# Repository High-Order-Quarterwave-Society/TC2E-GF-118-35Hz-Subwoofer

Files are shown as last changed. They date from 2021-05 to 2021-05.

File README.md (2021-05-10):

# Type C2E-GF-118 rev: 42.11
The TC2E-GF-118 Golden Formula Paraflex subwoofer was originaly designed by Matthew Morgan J. member of the **Higher Order Quarterwave Society** (HOQWS) which was started in 2013 by Matthew Morgan J, Dustin Morgan (Flex Tech Designs) and J. Vansickle (Paragon Concepts) 

### About Paraflex
The Paraflex subwoofer is based on a Low and High Tuned Resonator (LTR/HTR) making the design very efficient in it's bandwidth, which was named **Paraflex** for easy naming. Many prototypes and design revisions have been made by members of the HOQWS, continualy improving the design of the cabinet and its different versions.

The Golden Formula series of Paraflex subwoofers achieves improved performance by the use of a Throat Chamber in conjunction with an increased rate of expansion in the Low-Tuned Horn resonator section. This increased gain/sensitivity & output within the cabinet's working range, typically comes at the cost of sacrificing some surplus upper extension and can also often require a larger cabinet size. 

## Updates
The TC2E-GF-118 Revision 42.11 is the latest update for the TC2E-GF-118.

#### Folded High-Tune Resonator (HTR)
New 410mm long 45 degree angle-brace panels (which also serve as the folded & offset portion of the high-tuned resonator) have increased the upper frequency extension (cut-off) to 180hz and improved the cabinet's phase response, transient response, and impulse response, while reducing gd & decay times in the cabinet's upper working range above 80hz.

#### HTR filling
Acoustic damping material such as polyester fiberfill should be added to the angle braces. insert the damping material until it fills up 50% to 60% of the angle-brace's internal volume beginning from the end caps. 

#### Mouth brace update
A mouth brace has now been included to reduce flex in the mouth exit area, and with the updated merge bracing shape; a b&c 18ds115 is capable of fitting past on an angle. longer drivers will require shortening the brace or making it removable.

## Dimensions / Volume
Dimensions shall be 1200 x 915 x 600 milimeters and shall have 658 Liters Gross volume. The unloaded weight shall be 97Kg / 213Lbs.

## Working range
The TC2E-GF-118 has a 35Hz (Fb) tuning and the working range shall be 30hz to 180hz. Recomended crossover setting depends on the driver used, but a basic setting can be set with a 26-30hz 24dB/Butterworth Highpass filter (24dB/BW HPF) and a 75-160hz Butterworth 4th order low pass filter (24dB/BW LPF). We encourage the user to adjust the frequency range and filters based on their application.

## PDF
[You can download the PDF here](https://github.com/High-Order-Quarterwave-Society/TC2E-GF-118-35Hz-Subwoofer/blob/master/PARAFLEX%20C-2E%20Golden%20Formula%201x18%20v42.11.pdf)

## More...
Other designs using the Paraflex principles where made for midrange and infrasonic frequency ranges. There are always new concepts and designs in progress on the [HOQWS facebook page](https://www.facebook.com/groups/bassaz/).

*3D design by Ty Cention. (KaiRonex)*

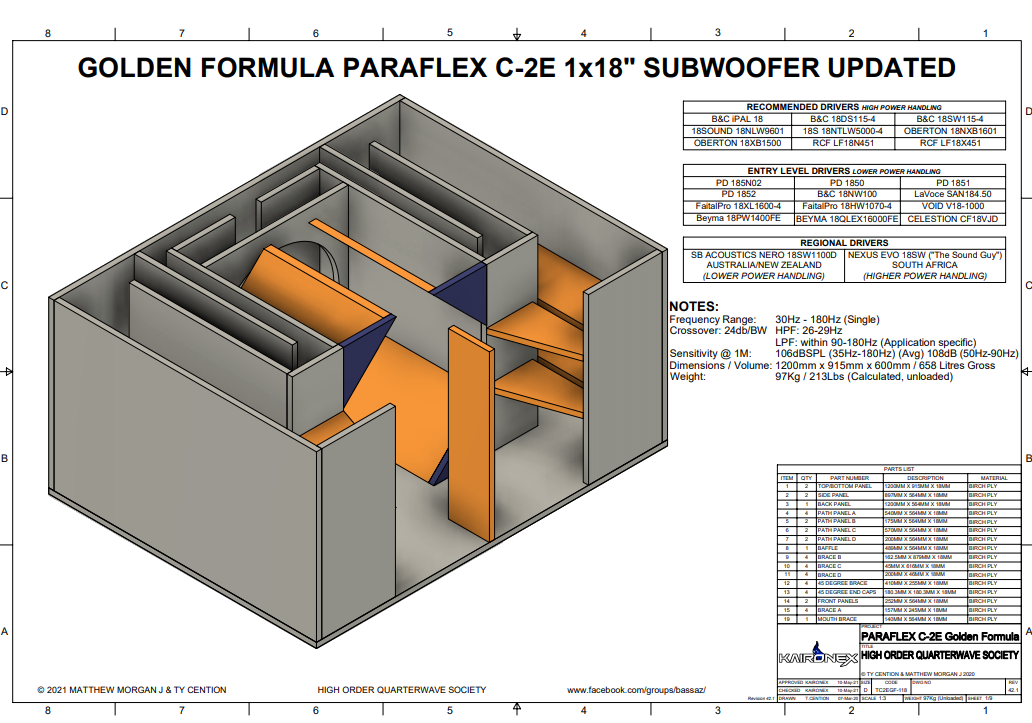
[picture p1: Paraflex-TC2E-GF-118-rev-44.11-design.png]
Design


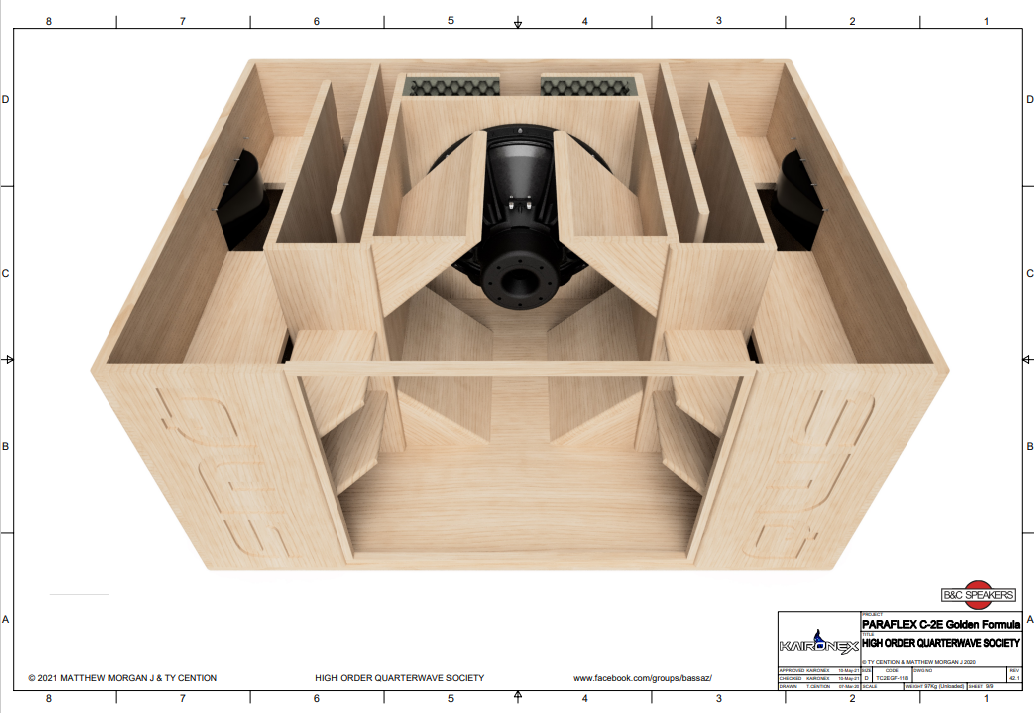
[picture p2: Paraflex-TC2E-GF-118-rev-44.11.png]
Modal view


 #### Honorable contributers and people from all arround the world who shared their knowledge, time, testing builds, prototyping, art work, design work and so much more to the HOQS group:
Ty Cention, Josh Mullins, Philip van Heijningen, Patrick Sander, Val Boodram, Justin Crescendo, Angel Garabitos Romero, Jason Geban, Andre Schrock, Casey Raynes, Conor Noakes, Nicolai Grymer and many more.

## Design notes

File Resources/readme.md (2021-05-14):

# Recources for the cabinet

CAD files, cutlists, CNC cut plans, etc.

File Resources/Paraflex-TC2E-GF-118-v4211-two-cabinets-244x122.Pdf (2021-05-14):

Birch 2440x1220x18 mm

Sheet Size : 2440 mm x 1220 mm

Cutting List

Symbol | Length | Width | Qty
1 | 1210 mm 925 mm | 2
2 | 670 mm 564 mm | 1
3 | 540 mm 564 mm | 1

# Job Layout

Job Reference : PARAFLEX-TC2E-GF-118 v42.11
Client Name : | Layout 1 of 6 (x1) - Birch 2440x1220x18 mm (2440 mm x 1220 mm)
Date Required : 27-5-2021 | Occurrences : 1 | Total Sheets : 6
Phone Number : | Sheet Panels : 4 | Job Panels : 76
Fax Number : | Layout Wastage : 1,88% | Job Wastage : 6,36%
Cell No : | Sheet Cut Length : 6632 mm | Job Cut Length : 73988 mm

1220 mm

2440 mm

1.TOP

1210 mm

925 mm

1.TOP

1210 mm

925 mm

2.PP C

670 mm

564 mm

3.PP A

540 mm

564 mm

### Grain Direction

### Occurrences

x1

Generated using MaxCut - visit www.maxcutsoftware.com to get your free copy | 14-5-2021

Cutting List

Symbol | Length | Width | Qty
1 | 1200 mm 915 mm | 2
2 | 670 mm 564 mm | 1
3 | 540 mm 564 mm | 1

Job Reference : PARAFLEX-TC2E-GF-118 v42.11
Client Name : | Layout 2 of 6 (x1) - Birch 2440x1220x18 mm (2440 mm x 1220 mm)
Date Required : 27-5-2021 | Occurrences : 1 | Total Sheets : 6
Phone Number : | Sheet Panels : 4 | Job Panels : 76
Fax Number : | Layout Wastage : 3,30% | Job Wastage : 6,36%
Cell No : | Sheet Cut Length : 6602 mm | Job Cut Length : 73988 mm
| 1220 mm

2440 mm

1.BOTTOM

1200 mm

915 mm

1.BOTTOM

1200 mm

915 mm

2.PP C

670 mm

564 mm

3.PP A

540 mm

564 mm

### Grain Direction

### Occurrences

x1

Cutting List

Symbol | Length | Width | Qty
1 | 1200 mm 564 mm | 2
2 | 897 mm 564 mm | 2
3 | 162,5 mm 879 mm | 1
4 | 252 mm 564 mm | 2
5 | 157 mm 245 mm | 1
6 | 200 mm | 46 mm | 3

Job Reference : PARAFLEX-TC2E-GF-118 v42.11
Client Name : | Layout 3 of 6 (x1) - Birch 2440x1220x18 mm (2440 mm x 1220 mm)
Date Required : 27-5-2021 | Occurrences : 1 | Total Sheets : 6
Phone Number : | Sheet Panels : 11 | Job Panels : 76
Fax Number : | Layout Wastage : 3,97% | Job Wastage : 6,36%
Cell No : | Sheet Cut Length : 11304 mm | Job Cut Length : 73988 mm
| 1220 mm

2440 mm

1.BACK

1200 mm

564 mm

1.BACK

1200 mm

564 mm

2.SIDE

897 mm

564 mm

2.SIDE

897 mm

564 mm

3.BR B 879 mm

162,5 mm

4.FP

252 mm

564 mm

4.FP

252 mm

564 mm

5.BR A 245 mm

157 mm

6.BR D 6.BR D 6.BR D

### Grain Direction

### Occurrences

x1

Cutting List

Symbol | Length | Width | Qty
1 | 489 mm 564 mm | 2
2 | 670 mm 564 mm | 2
3 | 897 mm 564 mm | 2
4 | 360 mm 564 mm | 2
5 | 45 mm | 616 mm | 2
6 | 200 mm | 46 mm | 2

Job Reference : PARAFLEX-TC2E-GF-118 v42.11
Client Name : | Layout 4 of 6 (x1) - Birch 2440x1220x18 mm (2440 mm x 1220 mm)
Date Required : 27-5-2021 | Occurrences : 1 | Total Sheets : 6
Phone Number : | Sheet Panels : 12 | Job Panels : 76
Fax Number : | Layout Wastage : 5,97% | Job Wastage : 6,36%
Cell No : | Sheet Cut Length : 12310 mm | Job Cut Length : 73988 mm
| 1220 mm

2440 mm

1.BAFFLE

564 mm

489 mm
1.BAFFLE

564 mm

489 mm

2.PP C

564 mm

670 mm

2.PP C

564 mm

670 mm

3.SIDE

564 mm

897 mm

3.SIDE

564 mm

897 mm

4.PP B

564 mm

360 mm
4.PP B

564 mm

360 mm

5.BR C 5.BR C 6.BR D 6.BR D

### Grain Direction

### Occurrences

x1

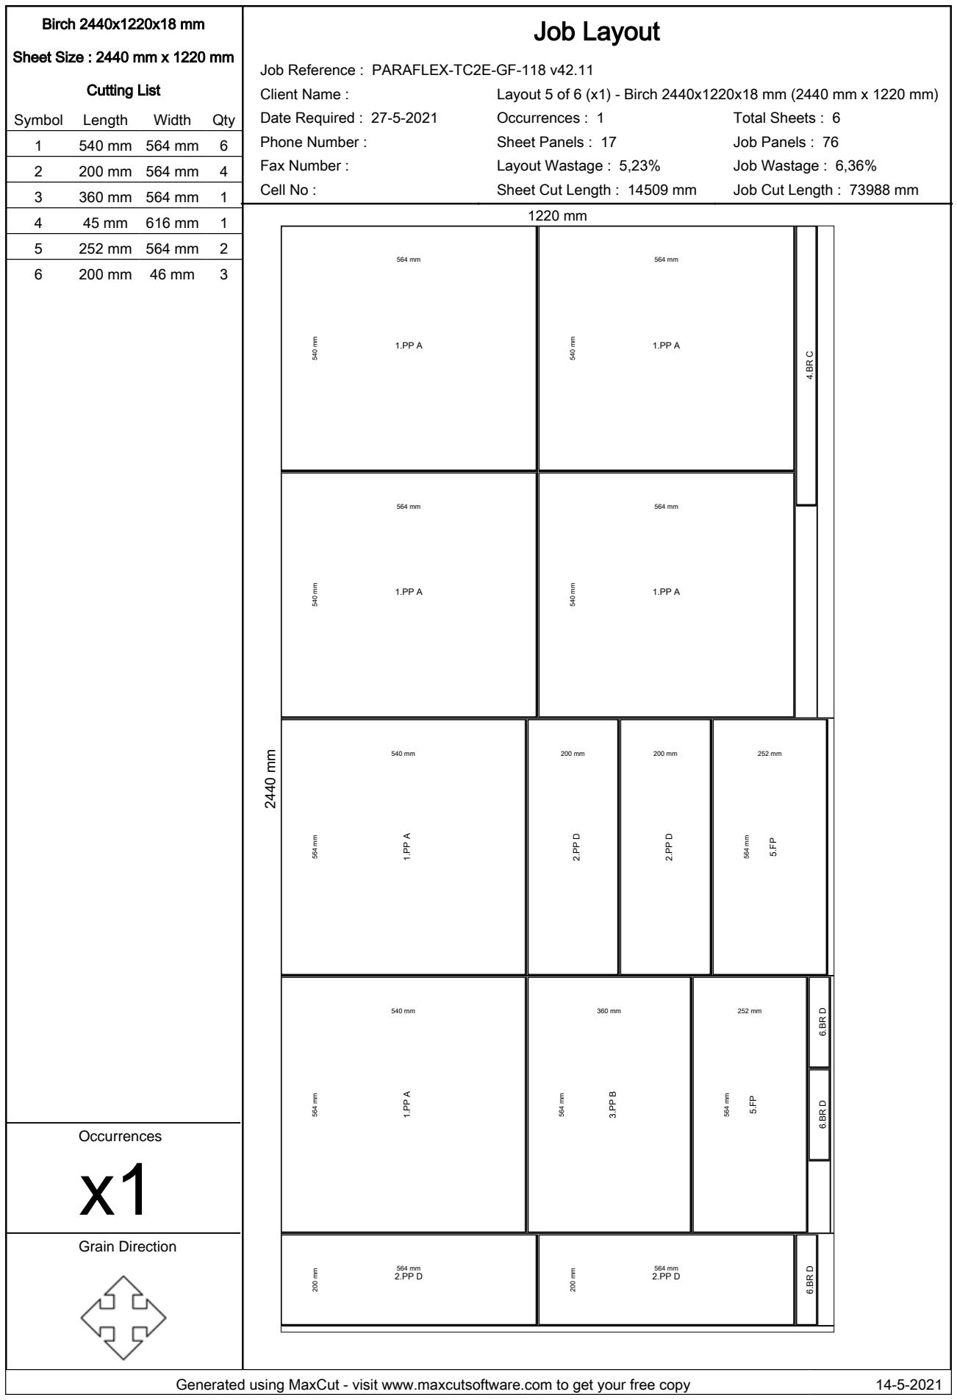
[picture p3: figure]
Cutting List; Symbol; Length; Width; Qty; Job Reference : PARAFLEX-TC2E-GF-118 v42.11; Date Required : 27-5-2021; Occurrences : 1; Total Sheets : 6; Phone Number :; Sheet Panels : 17; Job Panels : 76; Fax Number :; Layout Wastage : 5,23%; Job Wastage : 6,36%; Grain Direction; Occurrences x1

Client Name : | Layout 5 of 6 (x1) - Birch 2440x1220x18 mm (2440 mm x 1220 mm)
Cell No : | Sheet Cut Length : 14509 mm | Job Cut Length : 73988 mm

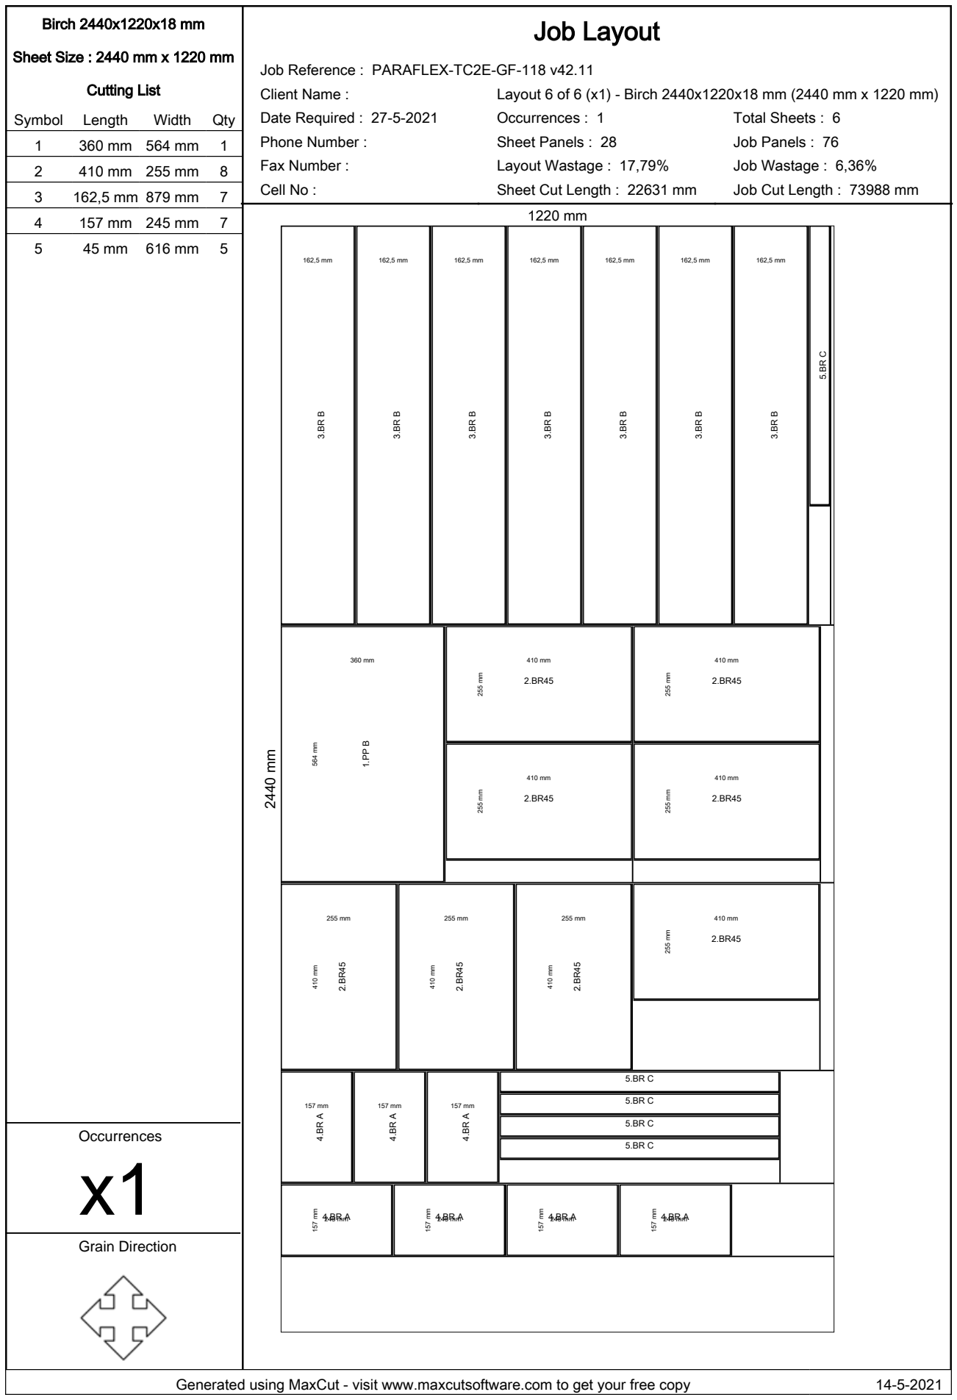
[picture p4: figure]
Cutting List; Symbol; Length; Width; Qty; Job Reference : PARAFLEX-TC2E-GF-118 v42.11; Date Required : 27-5-2021; Occurrences : 1; Total Sheets : 6; Phone Number :; Sheet Panels : 28; Job Panels : 76; Fax Number :; Layout Wastage : 17,79%; Job Wastage : 6,36%; Grain Direction; Occurrences x1

Client Name : | Layout 6 of 6 (x1) - Birch 2440x1220x18 mm (2440 mm x 1220 mm)
Cell No : | Sheet Cut Length : 22631 mm | Job Cut Length : 73988 mm

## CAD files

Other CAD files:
PARAFLEX C-2E Golden Formula Drawing v42.skp

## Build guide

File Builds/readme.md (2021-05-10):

# Build-logs TC2E-GF-118

A selection of Paraflex TC2E-GF-118 builds from around the world

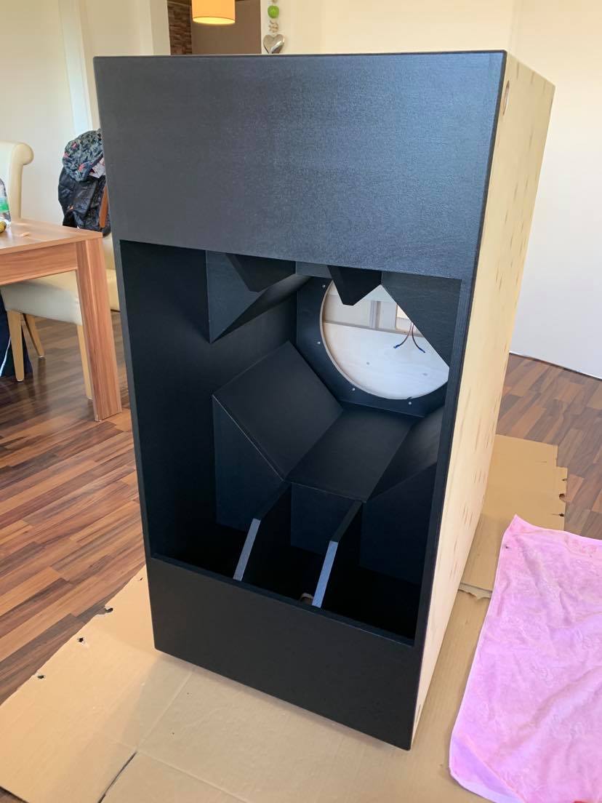
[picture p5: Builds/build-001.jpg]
builds-001

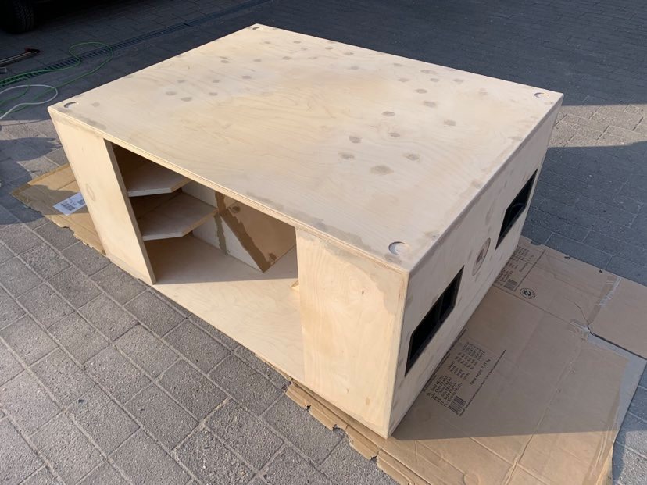
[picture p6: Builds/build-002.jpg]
builds-002

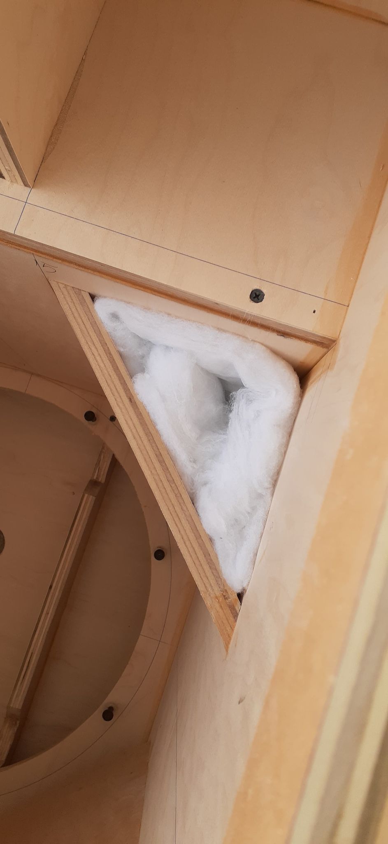
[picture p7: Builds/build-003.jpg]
builds-003

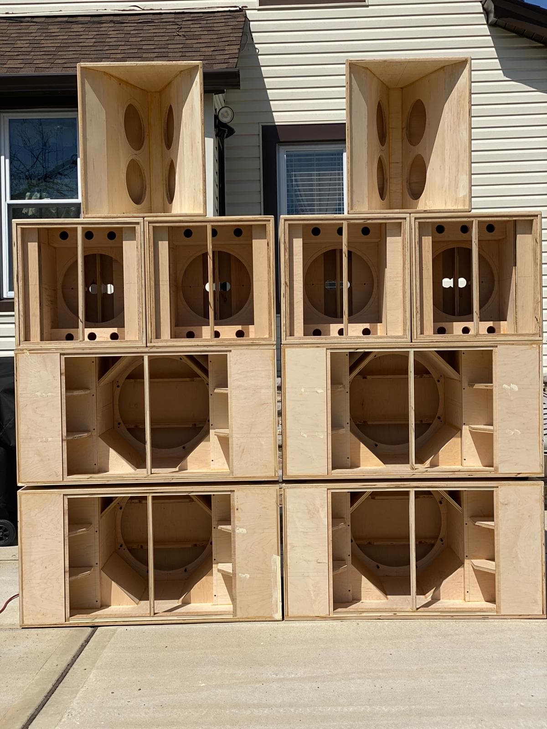
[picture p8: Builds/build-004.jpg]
builds-004

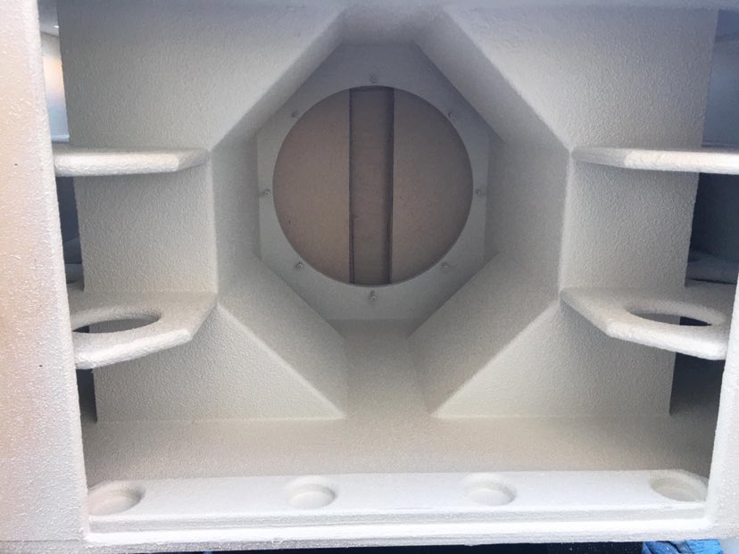
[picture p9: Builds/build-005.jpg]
builds-005

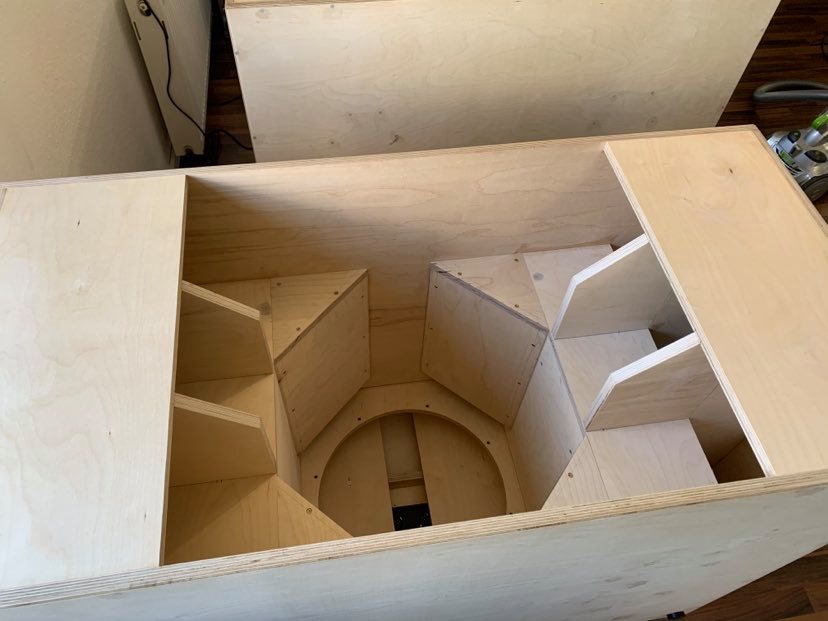
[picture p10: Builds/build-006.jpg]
builds-006

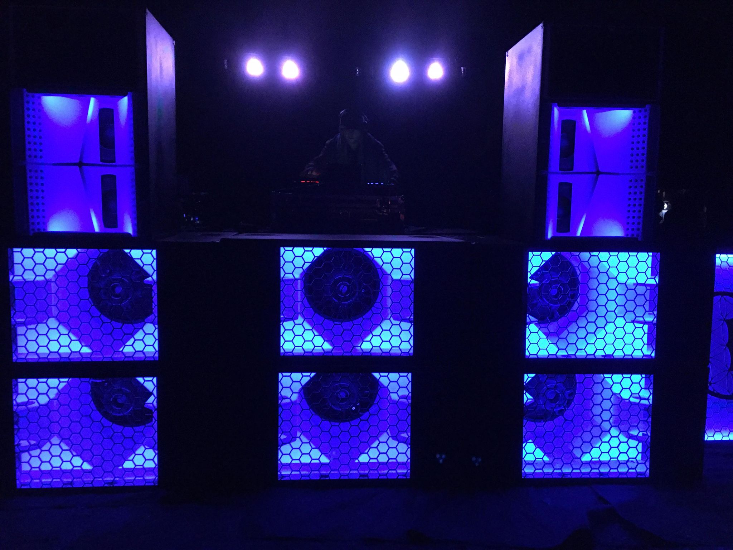
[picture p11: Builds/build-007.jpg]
builds-007

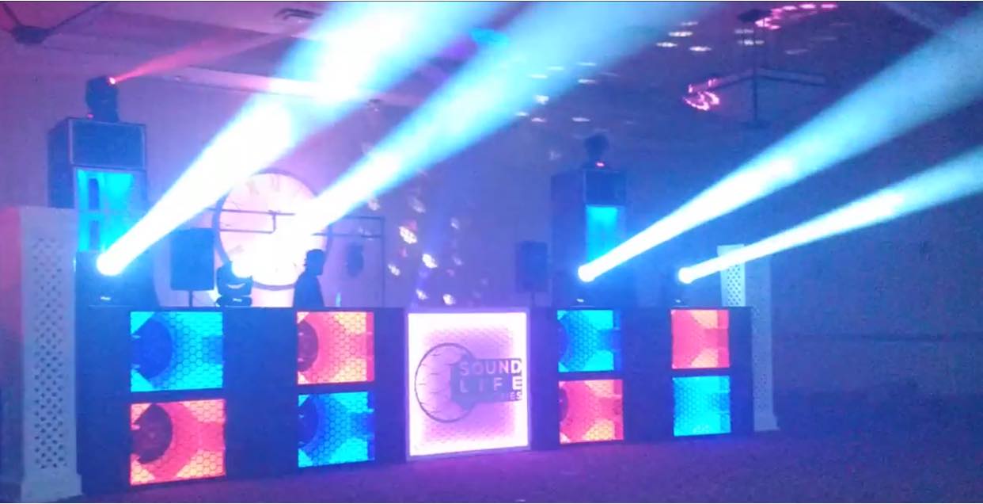
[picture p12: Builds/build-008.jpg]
builds-008


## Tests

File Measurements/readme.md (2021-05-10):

# Measurements of the Paraflex TC2E-GF-118

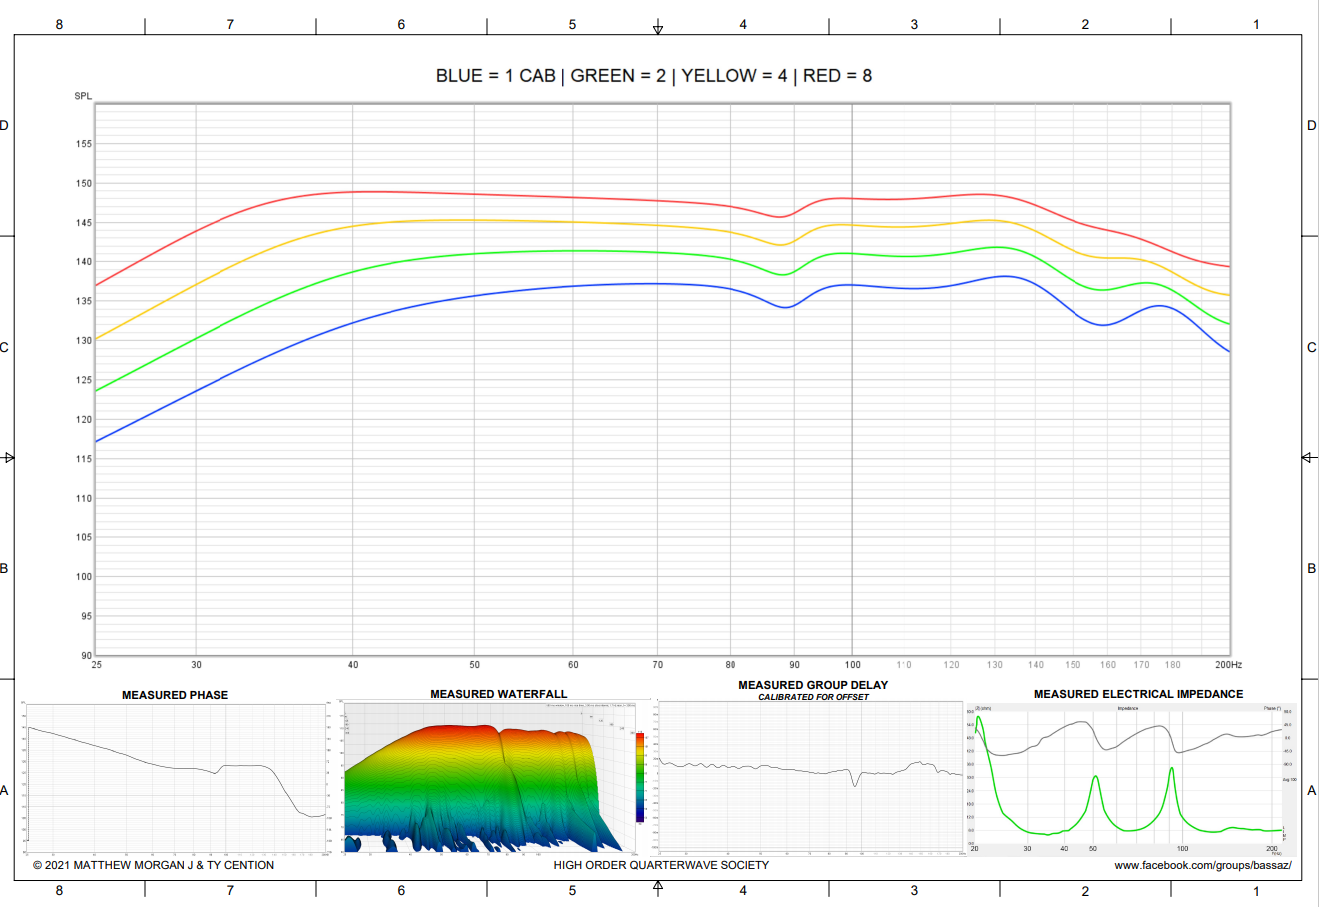
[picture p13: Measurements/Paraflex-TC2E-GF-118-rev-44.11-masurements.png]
measurement
